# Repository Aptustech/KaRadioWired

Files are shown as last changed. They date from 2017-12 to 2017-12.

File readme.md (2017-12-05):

The project log is available at : https://hackaday.io/project/28422-karadio-wired

The goal for this project is to have a high quality and repairable design. 

Power input is protected against reverse voltage connection and over voltage. I/O are protected against ESD. The design is based on 0603 sized components for easier manual soldering and repair. All meaningful signals are accessible on test points (solder side). Only the ethernet PHY is in QFN package.

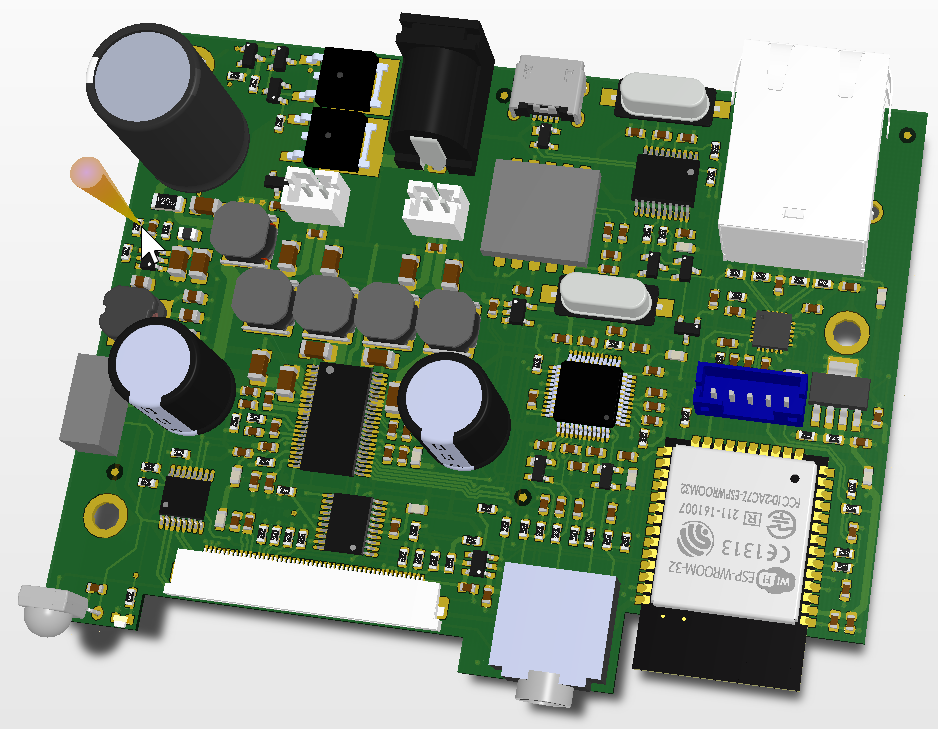
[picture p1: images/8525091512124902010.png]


Main features are :

- 2.4 inch Touch LCD 320x240

- 2x15W Class D amplifier

- VS1053 Audio decode to support all formats

- ESP32 with 100BT Ethernet for non stop streaming

- FM Radio receiver

- Rotary encoder for easy volume input

- IR receiver for remote control

- Groove compatible I2C connector for extension

- Developer friendly  with USB to UART connection

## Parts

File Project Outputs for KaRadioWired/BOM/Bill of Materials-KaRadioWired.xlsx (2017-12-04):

 |  | Component list |  | KaRadio Wired
 |  | Source Data From: |  | KaRadioWired.PrjPcb
 |  | Project: |  | KaRadio Wired | 01-open-001
 |  | Version: |  | 1.0
 |  | Report Date: | 12/3/2017 | 4:19:52 PM
 |  | Print Date: | 2017-12-03 | 16:20:21
Description | Case | Quantity | Designator | Manufacturer | PartNumber | Value | Voltage | Tolerance | Material
Aluminum Capacitor 470uF 25V TH 10mm 12.5mm |  | 2 | C1, C2 | United Chemi-Con | EKZN250ELL471MJC5S | 470uF | 25V | 20%
10nF 50V 1206 X7R | 1206 | 4 | C3, C6, C7, C8 |  |  | 10nF | 50V | 10% | X7R
4.7uF 50V 1206 X5R | 1206 | 3 | C4, C5, C65 |  |  | 4.7uF | 50V | 10% | X5R
100nF 25V 0603 X5R | 0603 | 24 | C9, C12, C17, C20, C31, C36, C40, C42, C43, C45, C46, C47, C49, C50, C51, C53, C54, C55, C57, C58, C59, C76, C80, C86 |  |  | 100nF | 25V | 10% | X5R
4.7uF 10V 0603 X5R | 0603 | 3 | C10, C11, C19 |  |  | 4.7uF | 10V | 10% | X5R
4.7nF 50V 0603 X7R | 0603 | 8 | C13, C16, C61, C83, C84, C85, C87, C89 |  |  | 4.7nF | 50V | 10% | X7R
47nF 50V 0603 X7R | 0603 | 4 | C14, C15, C24, C25 |  |  | 47nF | 50V | 10% | X7R
1uF 16V 0603 X7R | 0603 | 10 | C18, C30, C62, C63, C74, C75, C77, C78, C90, C91 |  |  | 1uF | 16V | 10% | X7R
2.2nF 50V 0603 X7R | 0603 | 3 | C21, C81, C82 |  |  | 2.2nF | 50V | 10% | X7R
2.2uF 10V 0603 X5R | 0603 | 4 | C22, C37, C41, C64 |  |  | 2.2uF | 10V | 10% | X5R
33pF 50V 0603 NP0 | 0603 | 4 | C23, C28, C29, C38 |  |  | 33pF | 50V | 10% | NP0
10nF 50V 0603 NP0 | 0603 | 3 | C26, C27, C66 |  |  | 10nF | 50V | 10% | NP0
680nF 50V 1206 C0G | 1206 | 4 | C32, C33, C34, C35 |  |  | 680nF | 50V | 10% | C0G
22uF 6.3V 0603 X5R | 0603 | 3 | C39, C44, C56 |  |  | 22uF | 6.3V | 10% | X5R
10uF 6.3V 0603 X5R | 0603 | 3 | C48, C52, C60 |  |  | 10uF | 6.3V | 10% | X5R
100nF 50V 0805 X5R | 0805 | 1 | C67 |  |  | 100nF | 50V | 10% | X5R
22uF 10V 0805 X5R | 0805 | 3 | C68, C69, C70 |  |  | 22uF | 10V | 10% | X5R
10uF 50V 1206 X5R | 1206 | 2 | C71, C72 |  |  | 10uF | 50V | 10% | X5R
68pF 50V 0603 NP0 | 0603 | 1 | C73 |  |  | 68pF | 50V | 10% | NP0
Aluminum Capacitor 1800uF 25V TH 12.5mm 20mm |  | 1 | C79 | United Chemi-Con | EGXF250ELL182MK20S | 1800uF | 25V | 20%
1nF 100V 1206 X7R | 1206 | 1 | C88 |  |  | 1nF | 100V | 10% | X7R
Side Emitting LED Blue |  | 1 | D1 | Kingbtigth | APA1606QBC/D
Ultra low capacitance double rail-to-rail ESD protection diode | SOT-143-B | 3 | D3, D4, D5 | Nexperia | PRTR5V0U2AX,215
DIODE ZENER 12V 250MW SOT23-3 | SOT23 | 2 | D6, D7 | ON Semi | BZX84C12LT1G
DIODE ZENER 22V 250MW SOT23-3 | SOT23 | 1 | D8 | ON Semi | BZX84C22LT1G
Connector for 240x320 dots 2.4" color tft lcd module |  | 1 | J1 | Amphenol FCI | 62684-501100ALF
SJ1-3524NG Jack 3.5mm Stereo |  | 1 | J2 | CUI | SJ1-3524NG
Modular Jack with Magnetics Shield LEDS RJLBC-060TC1 |  | 1 | J3 | TAIMAG | RJLBC-060TC1
Micro USB 2.0 SMT Type B Horizontal |  | 1 | J4 | Wurth Elektronik | 629105150521
CONN PWR JACK 2X5.5MM SOLDER |  | 1 | J5 | CUI | PJ-102AH
JST B2B-PH-K |  | 2 | J6, J7 | JST | B2B-PH-K
JST B5B-PH 2mm Pitch 5pins TH |  | 1 | J8 | JST | B5B-PH-K-S
1255AY-150M | 2424 | 4 | L1, L2, L3, L4 | Murata | 1255AY-150M | 15uH
SRN6045-100M 10uH 2.5A 6x6x4,5mm | 6045 | 1 | L5 | Bourns | SRN6045-100M | 10uH
0805, 600 Ohm@100MHz, 2.1A |  | 1 | L6 | Wurth | 74279220601 | 600 Ohm@100MHz
1255AY-4R7M=P3 4.7uH 4A | 2424 | 1 | L7 | Murata | 1255AY-4R7M=P3 | 4.7uH
SMD EMI Suppression Ferrite Bead WE-CBF, Z = 1000 Ohm |  | 12 | L8, L9, L10, L11, L12, L13, L14, L15, L16, L17, L18, L19 | Wurth | 742792662
ESP32_WROOM_32 |  | 1 | M1 | Espressif Systems | ESP32_WROOM_32
FM Receiver 11x11mm TEA5767 |  | 1 | M2 |  | MODULE_TEA5767
Male Header, Pitch 2 mm, 1 x 4 Position |  | 1 | P1 | JST | B4B-PH-K-S(LF)(SN)
BC817 NPN 45V SOT23 | SOT23 | 3 | Q1, Q2, Q3 | Nexperia | BC817-40,215
MOSFET P-CHANNEL 60V 7A TO252 |  | 2 | Q4, Q5 | Taiwan Semiconductor Corp | TSM7P06CP
MOSFET P-CH 60V 170MA SOT-23 |  | 1 | Q6 | Infineon | BSS84PH6433XTMA1
Resistor 470R 0603 1% | 0603 | 4 | R1, R2, R63, R64 |  |  | 470R |  | 1%
Resistor 18k 0603 1% | 0603 | 2 | R3, R41 |  |  | 18k |  | 1%
Resistor 100k 0603 1% | 0603 | 5 | R4, R12, R39, R55, R57 |  |  | 100k |  | 1%
Resistor 10k 0603 1% | 0603 | 23 | R5, R9, R10, R23, R26, R27, R33, R35, R36, R43, R44, R45, R46, R50, R51, R52, R56, R58, R59, R60, R61, R62, R65 |  |  | 10k |  | 1%
Resistor 10R 0603 1% | 0603 | 2 | R6, R31 |  |  | 10R |  | 1%
Resistor 20R 0603 1% | 0603 | 2 | R7, R8 |  |  | 20R |  | 1%
Resistor 1M 0603 1% | 0603 | 1 | R11 |  |  | 1M |  | 1%
Resistor 49R9 0603 1% | 0603 | 4 | R13, R14, R15, R16 |  |  | 49R9 |  | 1%
Resistor 12k1 0603 1% | 0603 | 2 | R17, R42 |  |  | 12k1 |  | 1%
Resistor 68R 0603 1% | 0603 | 10 | R18, R19, R20, R21, R24, R25, R28, R29, R30, R32 |  |  | 68R |  | 1%
Resistor 11k 0603 1% | 0603 | 1 | R22 |  |  | 11k |  | 1%
Resistor 1k 0603 1% | 0603 | 5 | R34, R47, R48, R49, R53 |  |  | 1k |  | 1%
Resistor 4k7 0603 1% | 0603 | 2 | R37, R38 |  |  | 4k7 |  | 1%
Resistor 17k8 0603 1% | 0603 | 1 | R40 |  |  | 17k8 |  | 1%
Resistor 0.25R 1206 1% | 1206 | 1 | R54 |  |  | 0R25 |  | 1%
TAS5751M - Digital Input Audio Power Amplifier with EQ and 3-Band AGL | TSSOP48 | 1 | U1 | TI | TAS5751M
CH340T USB to Serial | TSOP20 | 1 | U2 | WCH | CH340T
VS1053 DSP | TQFP48 | 1 | U3 | VLSI | VS1053b
LAN8720 RMII 10/100 Ethernet Transceiver QFN24 | QFN24 | 1 | U4 | Microchip | LAN8720A-CP-ABC
TSSOP I2C Resistive Touch Controller | TSOP16 | 1 | U5 | TI | TSC2007IPWR
TPS730 ADJ 200mA SOT23-6 LDO | SOT23-6 | 1 | U6 | TI | TPS73001DBV
4.5V to 28V Input, 2A Output Sync Buck | SOT23-6 | 1 | U7 | TI | TPS54202DDC
1.8V LDO 50mA SOT23-5 | SOT23-5 | 1 | U8 | Microchip | TC1014-1.8VCT713
REG LIN POS ADJ 1A SOT223-5 LP38692MP-ADJ/NOPB | SOT223-5 | 1 | U9 | TI | LP38692MP-ADJ/NOPB
PCF8574TS/3 SSOP20 I2C I/O Expander | SSOP20 | 1 | U10 | NXP | PCF8574TS/3
TSOP33436 IR 36kHz Receiver |  | 1 | U11 | Vishay | TSOP33436
Reset 2.93V open drain sot23 MIC803-29D3VM3-TR | SOT23 | 1 | U12 | Microchip | MIC803-29D3VM3-TR
SOT23-5 USB VCC Switch with current Limit | SOT23-5 | 1 | U13 | Silergy | SY6280A
12.2880MHz Crystal HC49 SMT 50ppm | HC49S | 1 | Y1 | Fox Electronic | FOXSDLF/128-20 | 12.2880MHz |  | 50ppm
12.0000MHz Crystal HC49 SMT 20ppm | HC49S | 1 | Y2 | Diodes | GC1200052 | 12MHz |  | 20ppm

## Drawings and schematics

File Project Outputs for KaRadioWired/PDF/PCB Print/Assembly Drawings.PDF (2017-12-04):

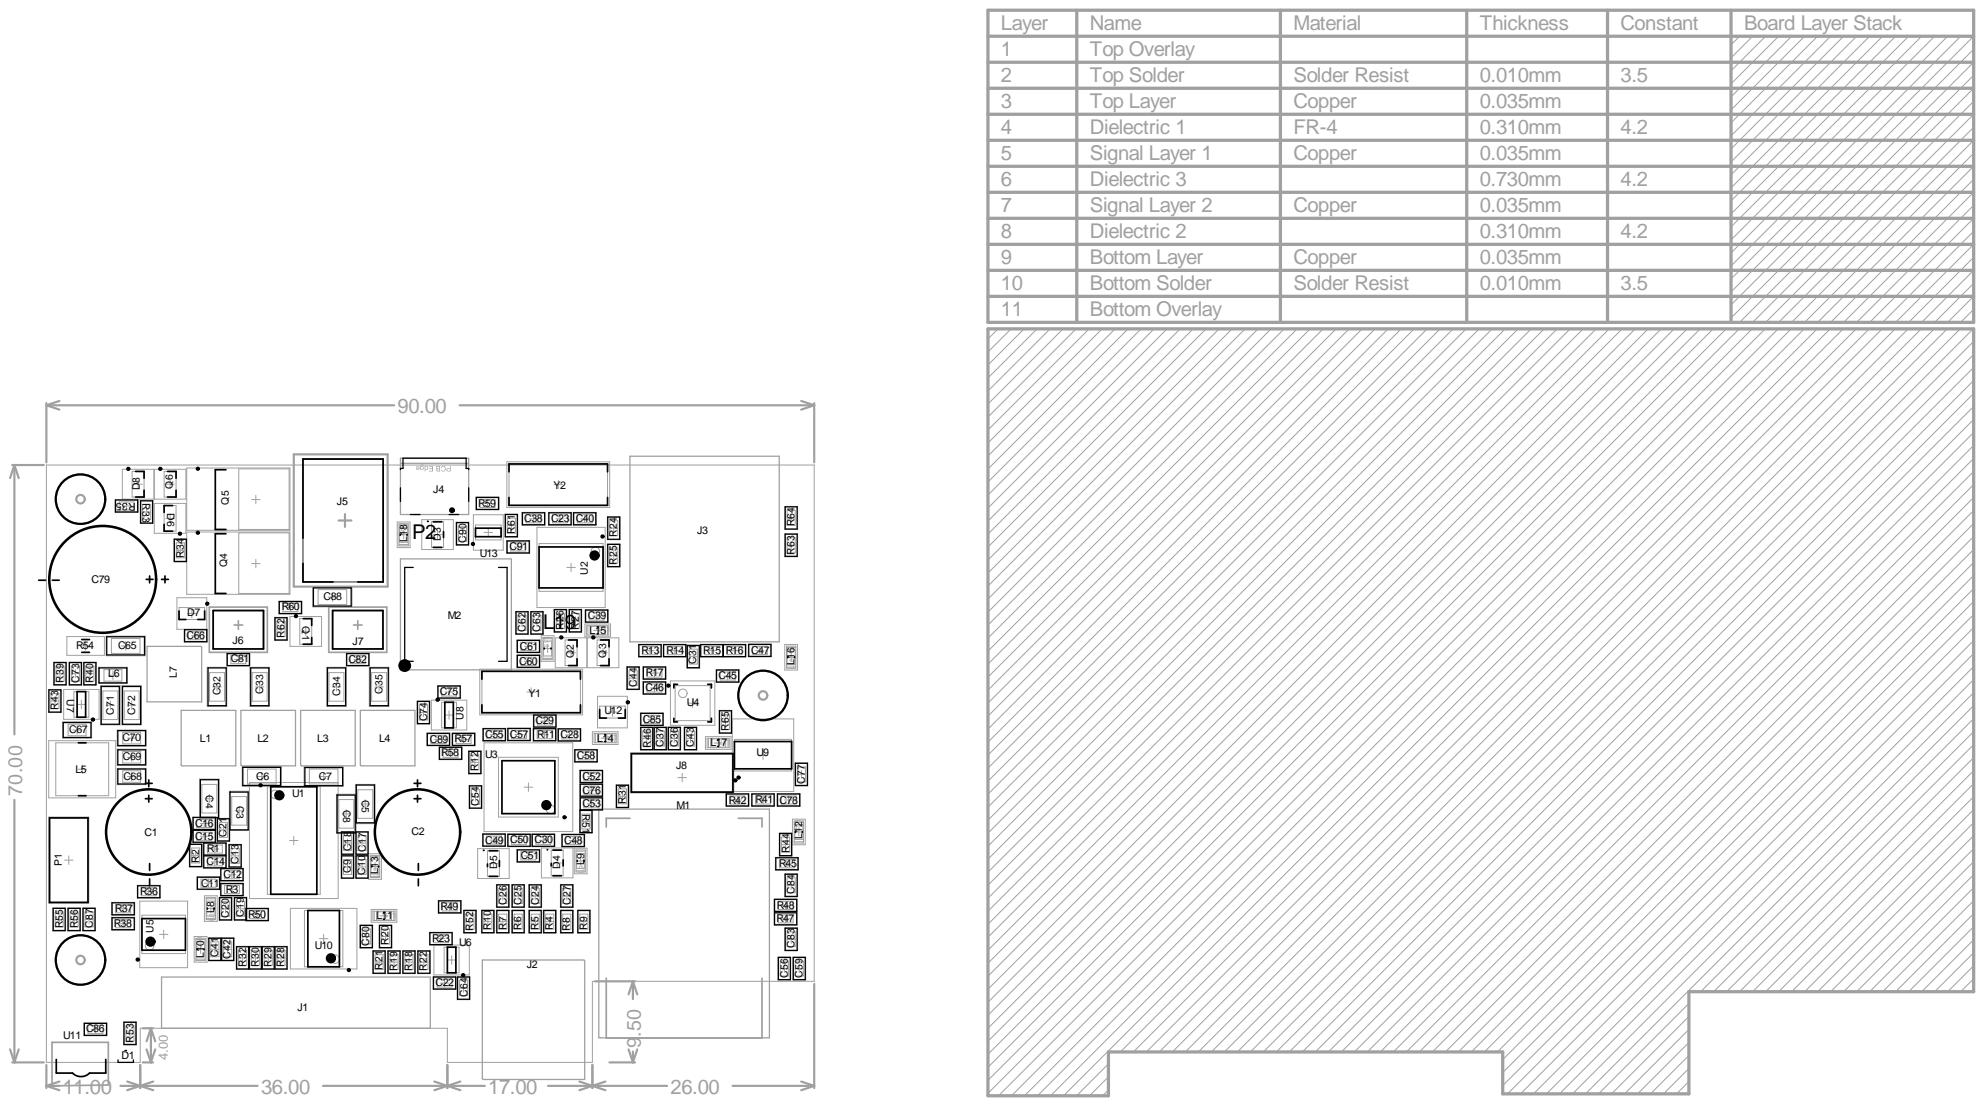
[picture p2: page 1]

Layer | Name | Material | Thickness | Constant | Board Layer Stack
1 | Top Overlay
2 | Top Solder | Solder Resist | 0.010mm | 3.5
3 | Top Layer | Copper | 0.035mm
4 | Dielectric 1 | FR-4 | 0.310mm | 4.2
5 | Signal Layer 1 | Copper | 0.035mm
6 | Dielectric 3 | | 0.730mm | 4.2
7 | Signal Layer 2 | Copper | 0.035mm
8 | Dielectric 2 | | 0.310mm | 4.2
9 | Bottom Layer | Copper | 0.035mm
10 | Bottom Solder | Solder Resist | 0.010mm | 3.5
11 | Bottom Overlay

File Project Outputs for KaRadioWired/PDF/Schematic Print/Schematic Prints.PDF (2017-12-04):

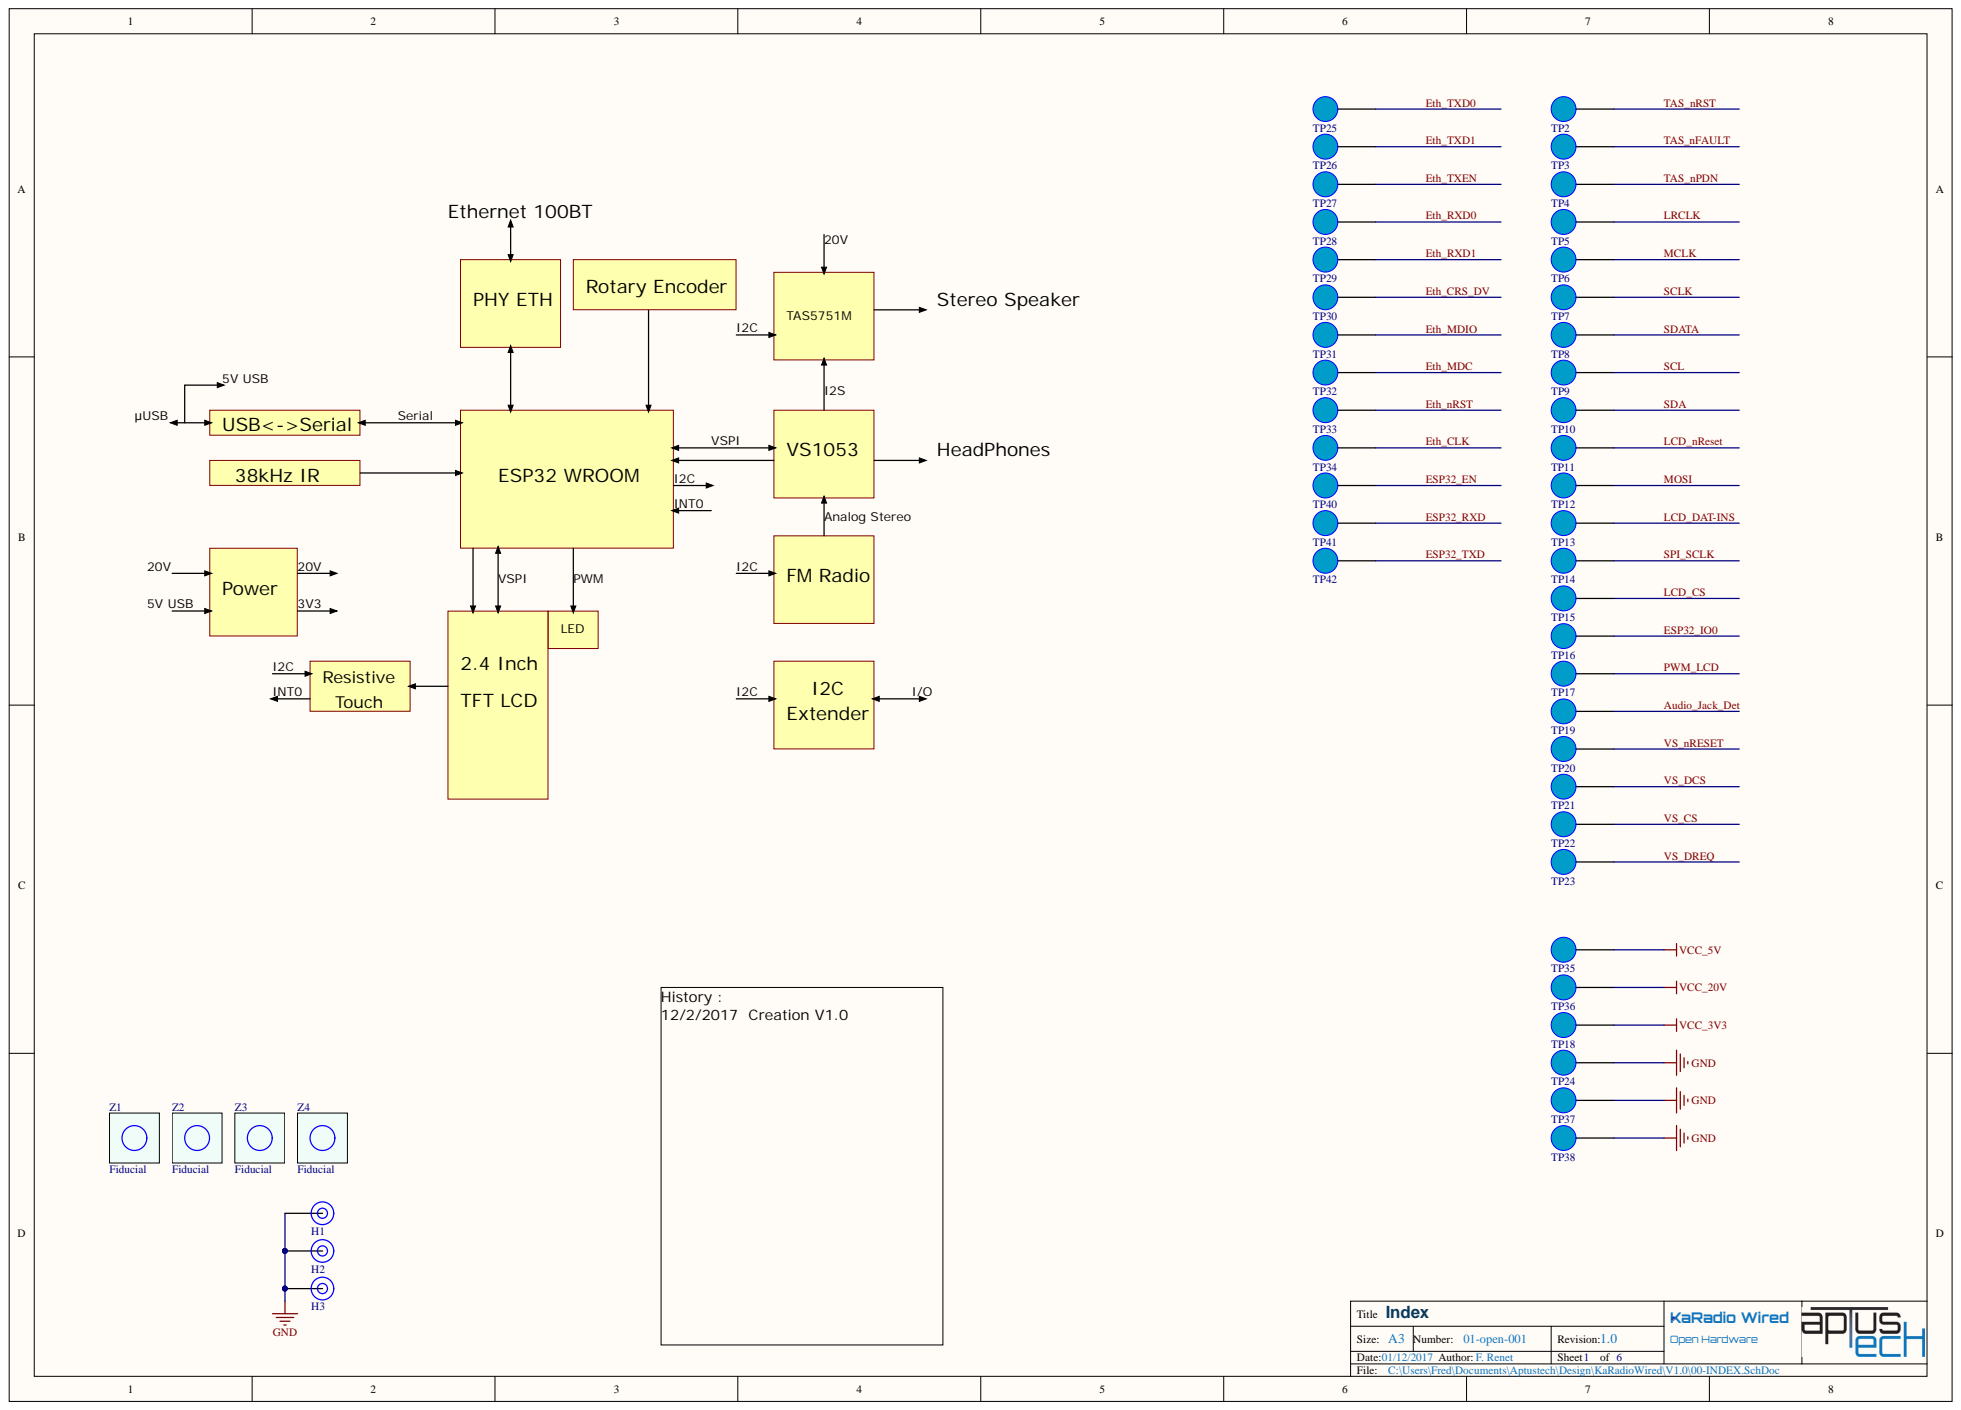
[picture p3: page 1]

Index Title | K* aRadio Wire d Open H a rdw a r e

Size: A3 | Number: 01-open-001 | Revision: 1.0

Date: Author: F. Renet | | Sheet of

C:\Users\Fred\Documents\Aptustech\Design\KaRadioWired\V1.0\00-IN

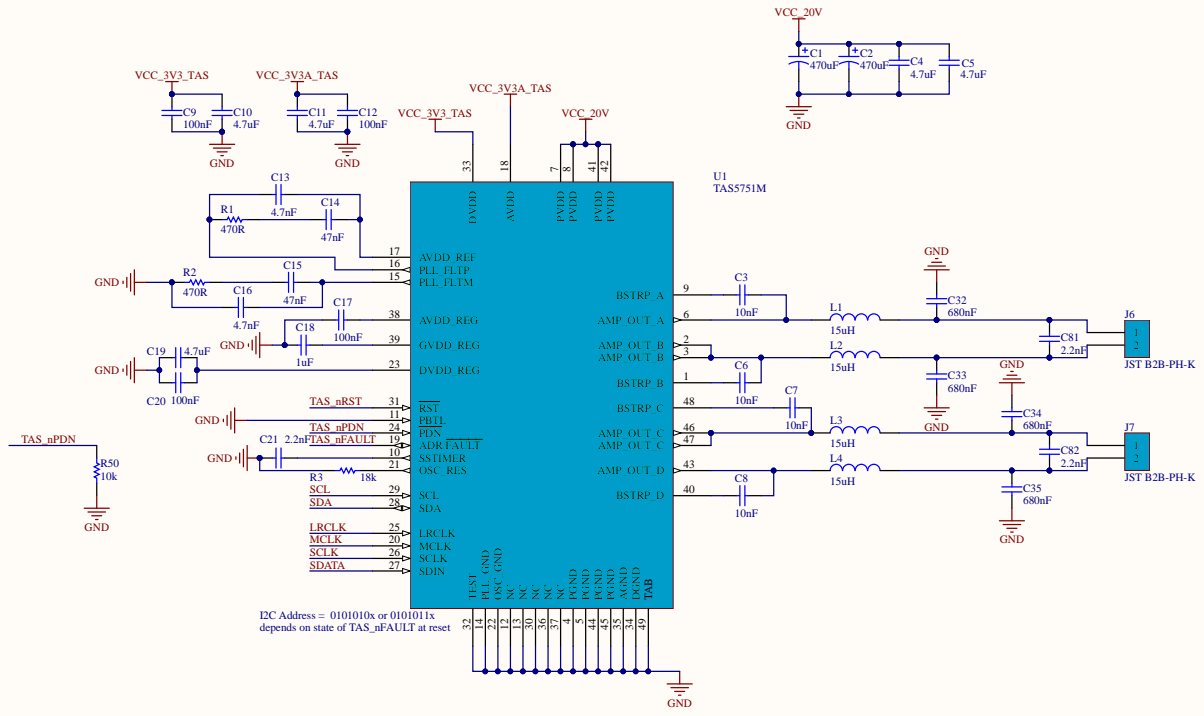
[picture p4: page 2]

depends on state of

Amplifier TAS5751M | K* aRadio Wire d Open H a rdw a r e

Size: | Number:

C:\Users\Fred\Documents\Aptustech\Design\KaRadioWired\V1.0\01-Amplifier.SchDoc

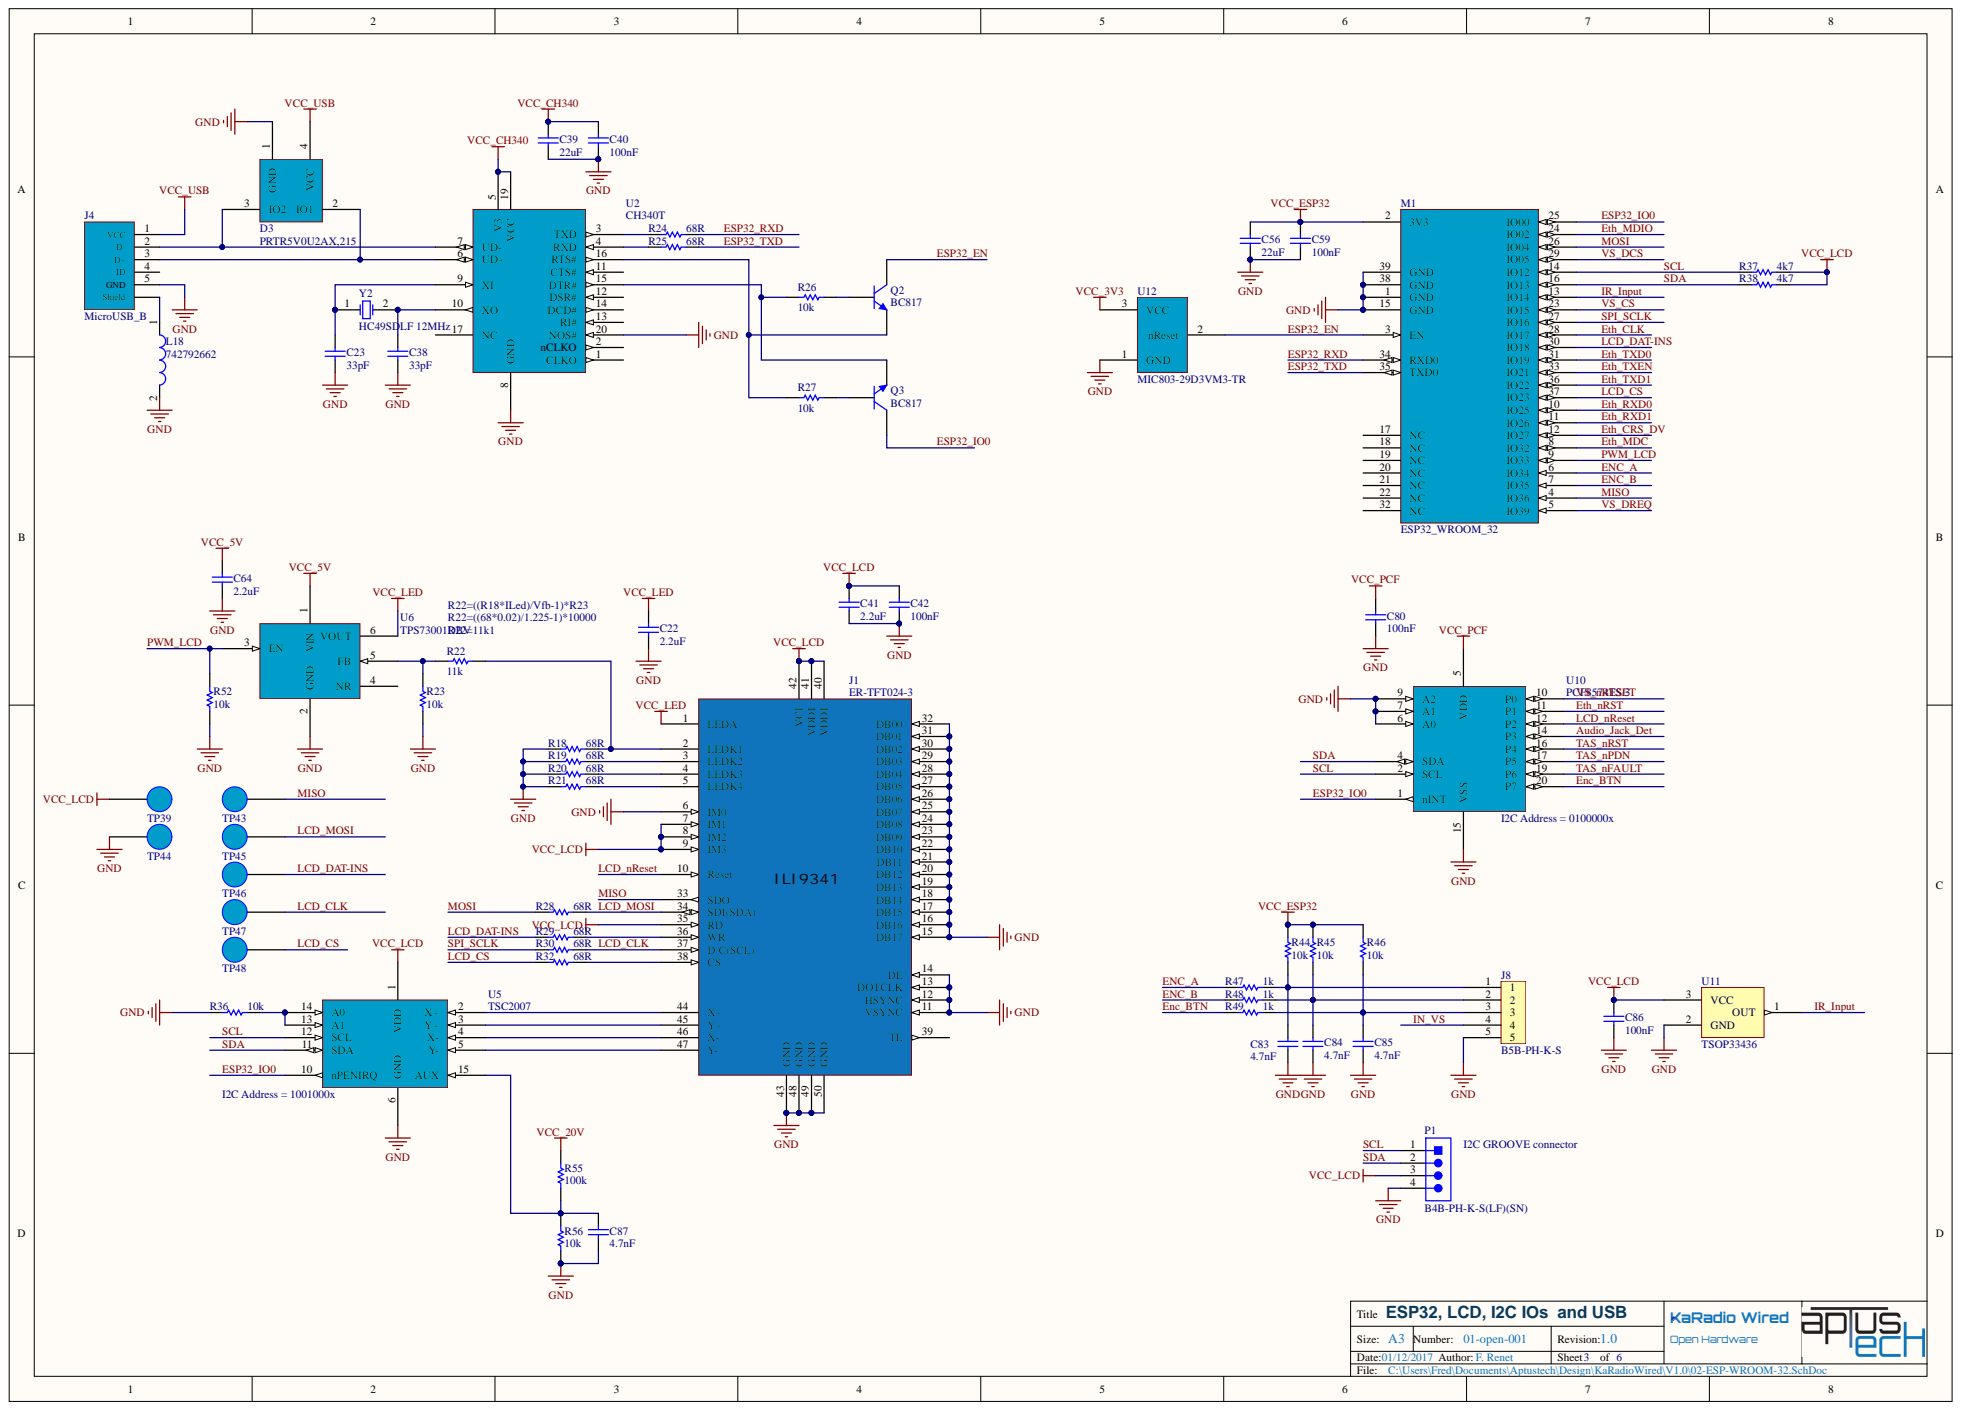
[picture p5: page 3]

ESP32, LCD, I2C IOs and USB | K* aRadio Wired Open Hardware

Size: | Number:

C:\Users\Fred\Documents\Aptustech\Design\KaRadioWired\V1.0\02-ESP-WROOM-32.SchDoc

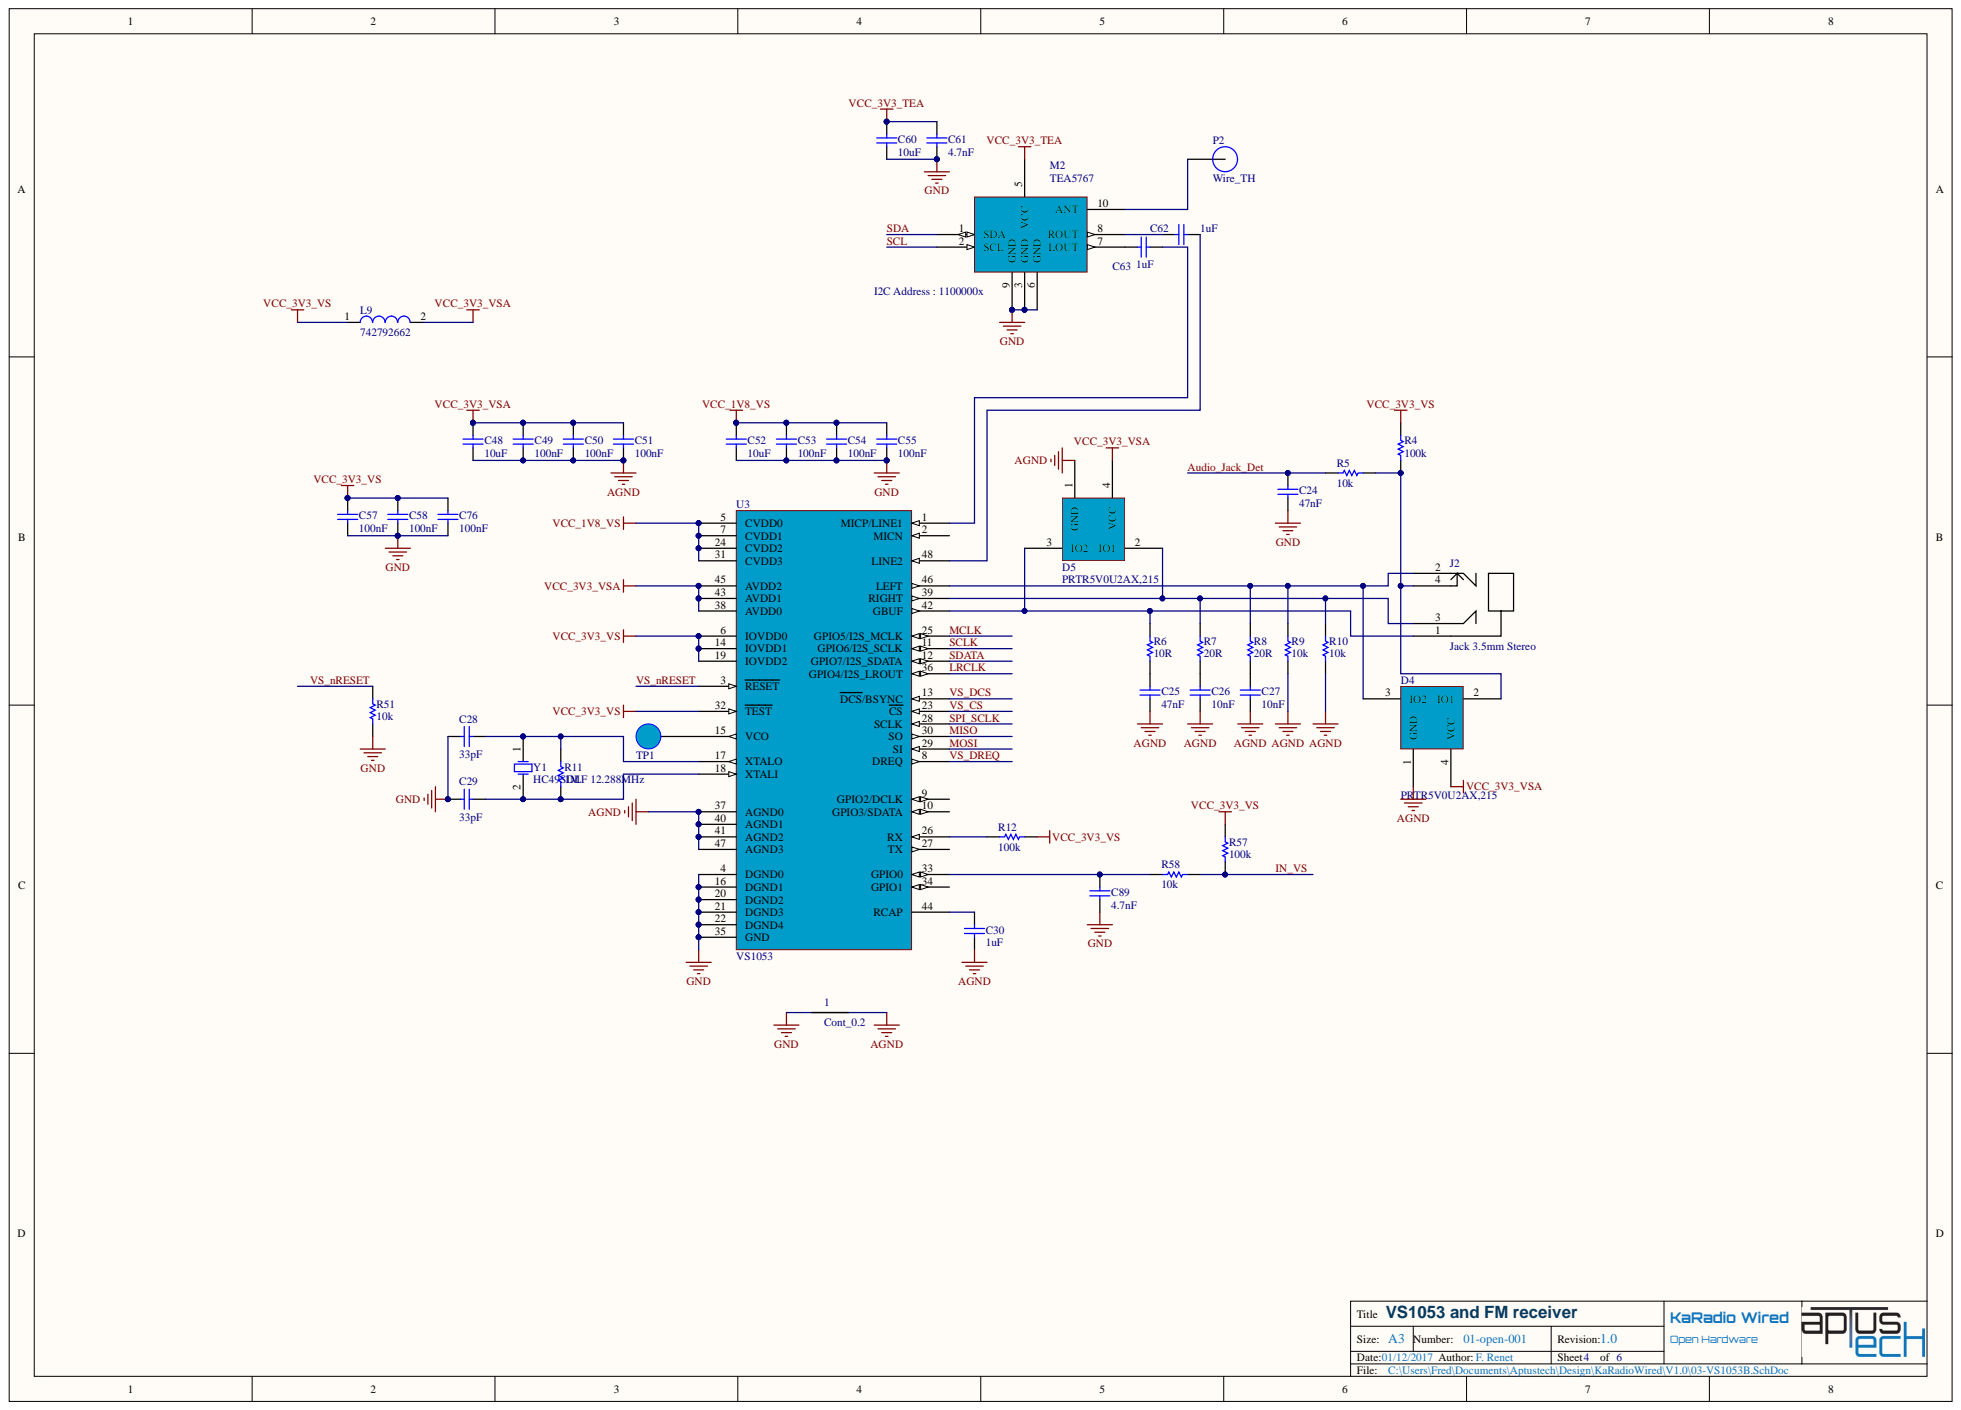
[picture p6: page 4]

IOVDD1 14 | SCLK R6 | Jack 3.5mm Stereo 10k D4
IOVDD2 19 | SDATA

C:\Users\Fred\Documents\Aptustech\Design\KaRadioWired\V1.0\03-VS1053B.SchDoc

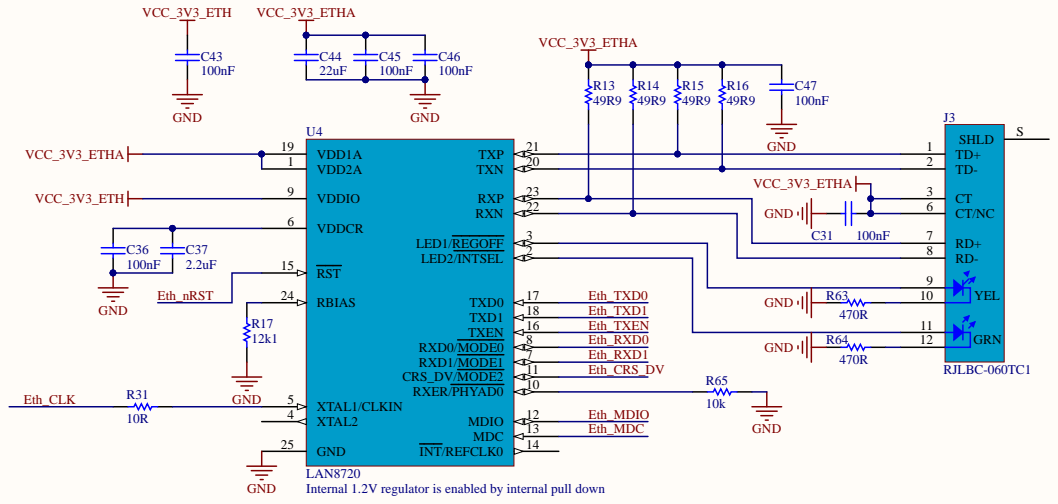
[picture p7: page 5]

VDD2A 1 | | | TD- 2

VDDCR 6 | | | | | CT/NC 6

RST 15

Eth_nRST | RBIAS 24

Eth_TXEN | | 10

XTAL2 4 XTAL1/CLKIN 5 | | | 11

LAN8720
Internal 1.2V regulator is enabled by internal pull down

C:\Users\Fred\Documents\Aptustech\Design\KaRadioWired\V1.0\04-Ethernet.SchDoc

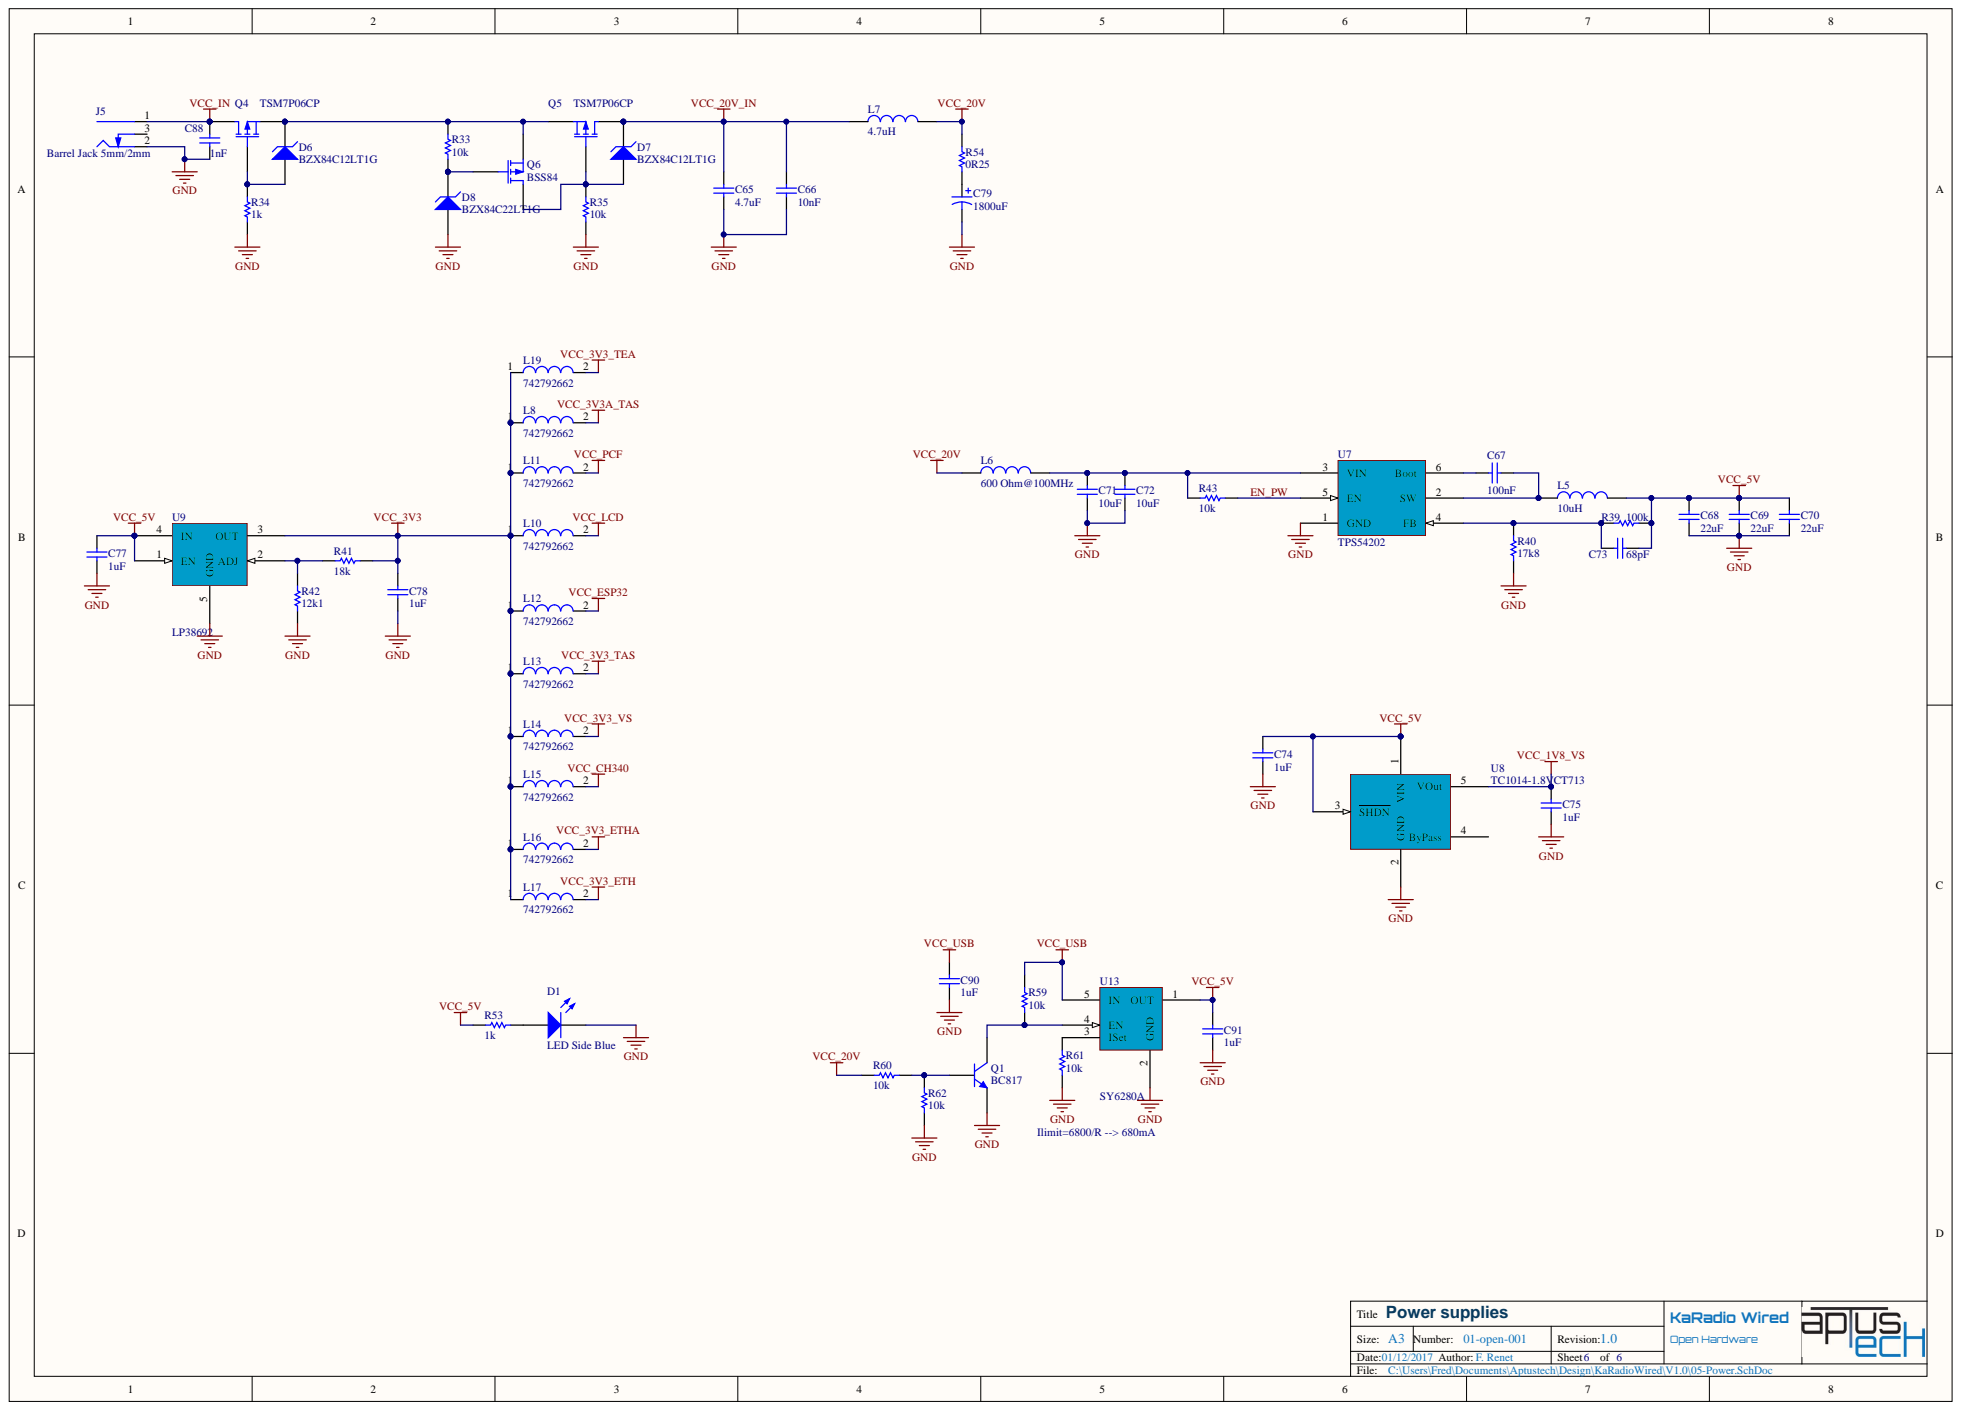
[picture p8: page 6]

BSS84

C:\Users\Fred\Documents\Aptustech\Design\KaRadioWired\V1.0\05-Power.SchDoc
